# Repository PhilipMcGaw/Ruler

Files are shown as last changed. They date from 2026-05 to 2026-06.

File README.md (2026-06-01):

# Ruler

A KiCad PCB ruler that doubles as a desk reference for SMD footprints, drill sizes, and trace widths—and includes a small ATtiny85 circuit to light five LEDs. Designed by [Philip McGaw](https://philipmcgaw.com).

The board is roughly **100 mm** long and combines measurement scales with populated example parts you can touch, compare, and (optionally) program.

## Features

### Measurement & reference

- **Metric** and **imperial** ruler scales (including 1/8″ and 1/10″ subdivisions)
- **Degree / protractor** scale for rough angle checks
- **Drill hole** reference sizes
- **Trace width** and **font size** guides (mm and mil)
- **SMD resistor** footprints from 0201 through 2512, with separate **hand-solder** and **machine-solder** pad variants
- **SMD LED** examples (0201, 0402, 0603, 0805, 1206)
- **Test points** labelled for common pad/hole diameters (1.0–2.5 mm)

### Electronics

| Item | Details |
|---|---|
| MCU | ATtiny85V-10SU (SOIJ-8) |
| LEDs | Five, one per common SMD size (red 1206, green 0402, yellow 0603, orange 0805, blue 0201) |
| Power | CR2032 coin cell (Keystone 3002 holder) |
| Programming | 2×3 pin header (`J1`, labelled ICP6) for in-circuit programming |

The populated LEDs are driven by the ATtiny85. **Firmware is not included in this repository**—you will need to write and flash your own sketch (e.g. with [Arduino IDE + ATTinyCore](https://github.com/SpenceKonde/ATTinyCore) or `avrdude` via the ISP header).

> **Note:** This ruler is intended as a **reference and teaching aid**, not a calibrated measuring instrument.

## Repository layout

```
KiCAD/
├── ruler.kicad_pro      # KiCad project
├── ruler.kicad_sch      # Schematic
├── ruler.kicad_pcb      # Board layout
├── Common/              # Project symbols, footprints, design blocks
│   ├── Symbols.kicad_sym
│   ├── Footprints/      # Custom footprints (SquashedFly — https://squashedfly.eu/)
│   └── Design Blocks/
├── Libraries/           # Additional third-party symbol/footprint libraries
├── sym-lib-table
├── fp-lib-table
└── design-block-lib-table
```

Gerber output is configured to write to `KiCAD/Gerber/` when you plot from Pcbnew.

## Requirements

- **[KiCad](https://www.kicad.org/)** 9 or 10 (project files were last saved with KiCad 10)
- **PCBRulers** footprint library — the board uses footprints such as `PCBRulers:Metric_Ruler_96mm`, `PCBRulers:Inch_Ruler_3.5in_10`, `PCBRulers:Drills`, and `PCBRulers:Degree_Scale`. Install the [PCBruler](https://github.com/jbtronics/PCBruler) library (or equivalent) and add it to your KiCad footprint library path if footprints appear missing.
- Standard KiCad libraries for passives, connectors, batteries, and the ATtiny symbol (project rescue lib `ruler-rescue` is embedded in the schematic)

## Opening the project

1. Clone this repository.
2. Open `KiCAD/ruler.kicad_pro` in KiCad.
3. If prompted about missing libraries, confirm that `Common/` paths resolve (they use `${KIPRJMOD}`) and that **PCBRulers** is installed globally or added to `fp-lib-table`.

Project-local tables already point at bundled assets:

- Symbols: `Common/Symbols.kicad_sym`, Partsbox HTTP lib
- Footprints: `Common/Footprints/`

## Building the board

1. Run **Design Rules Check** (DRC) in Pcbnew and resolve any issues for your fab’s capabilities.
2. Generate manufacturing files: **File → Plot** (Gerbers) and **File → Fabrication Outputs → Drill Files**.
3. Order from your preferred PCB fab. For best readability of the silkscreen scales and contact details, **ENIG** finish and a dark soldermask are commonly used on similar rulers.

Populate the optional electronics if you want the LED demo to work; the ruler scales and footprint references are useful even unpopulated.

## Programming the ATtiny85

1. Connect an ISP programmer to `J1` (6-pin, 2.54 mm pitch, 2×3).
2. Power the board from the CR2032 cell or according to your programmer’s requirements.
3. Flash firmware with your toolchain of choice.

Pin mapping and LED connections are defined in `ruler.kicad_sch` / `ruler.kicad_pcb`.

## Credits

- **Design:** Philip McGaw — [philipmcgaw.com](https://philipmcgaw.com) · [GitHub](https://github.com/PhilipMcGaw)
- **[SquashedFly](https://squashedfly.eu/)** — title block worksheet (`KiCAD/Common/Squashed Fly.kicad_wks`) and optional PCB logo footprints (`SquashedFlySilk`, `SquashedFlyCopper`, etc.) in `KiCAD/Common/Footprints/`
- Ruler scale footprints from the **PCBRulers** / [PCBruler](https://github.com/jbtronics/PCBruler) ecosystem

## License

Hardware design files in this repository are licensed under the **[CERN Open Hardware Licence v2 — Strongly Reciprocal (CERN-OHL-S-2.0)](LICENSE)**, an open source hardware license recommended by the [Open Source Hardware Association (OSHWA)](https://oshwa.org/).

- **SPDX identifier:** `CERN-OHL-S-2.0`
- **Copyright:** [Philip McGaw](https://philipmcgaw.com/)
- **Full text:** [LICENSE](LICENSE)

You may use, study, modify, and redistribute the schematic and PCB layout under those terms. **Derivative designs must be released under the same license.** If you share the design or boards built from it, include a copy of the license.

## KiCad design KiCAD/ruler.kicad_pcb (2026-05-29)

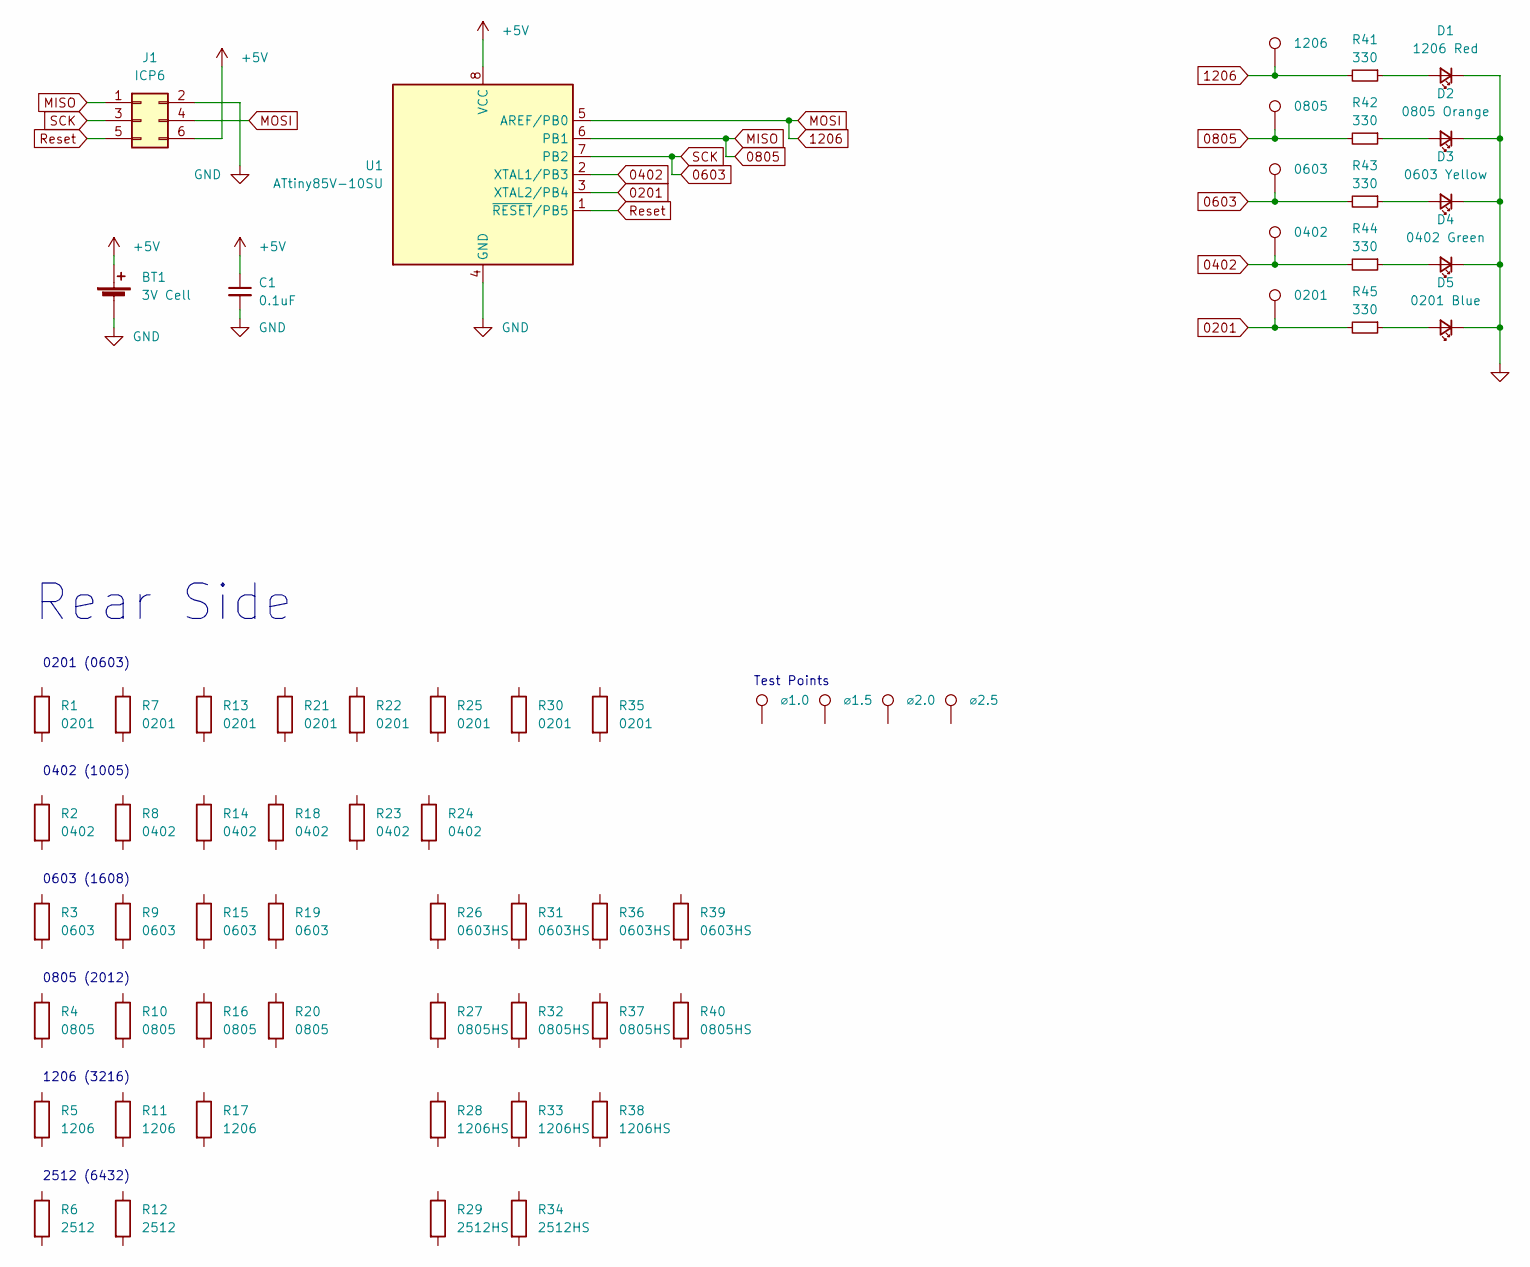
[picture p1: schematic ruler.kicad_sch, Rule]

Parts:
BT1: 3V Cell; BatteryHolder_Keystone_3002_1x2032
C1: 0.1uF; C_0805_2012Metric_Pad1.15x1.40mm_HandSolder
D1: 1206 Red; LED_1206_3216Metric_Pad1.42x1.75mm_HandSolder
D2: 0805 Orange; LED_0805_2012Metric_Pad1.15x1.40mm_HandSolder
D3: 0603 Yellow; LED_0603_1608Metric_Pad1.05x0.95mm_HandSolder
D4: 0402 Green; LED_0402_1005Metric
D5: 0201 Blue; LED_0201_0603Metric
J1: ICP6; PinHeader_2x03_P2.54mm_Vertical
R1, R7, R13, R21, R22, R25, R30, R35: 0201; R_0201_0603Metric
R2, R8, R14, R18, R23, R24: 0402; R_0402_1005Metric
R3, R9, R15, R19: 0603; R_0603_1608Metric
R4, R10, R16, R20: 0805; R_0805_2012Metric
R5, R11, R17: 1206; R_1206_3216Metric
R6, R12: 2512; R_2512_6332Metric
R26, R31, R36, R39: 0603HS; R_0603_1608Metric_Pad0.98x0.95mm_HandSolder
R27, R32, R37, R40: 0805HS; R_0805_2012Metric_Pad1.20x1.40mm_HandSolder
R28, R33, R38: 1206HS; R_1206_3216Metric_Pad1.30x1.75mm_HandSolder
R29, R34: 2512HS; R_2512_6332Metric_Pad1.40x3.35mm_HandSolder
R41: 330; R_1206_3216Metric_Pad1.42x1.75mm_HandSolder
R42: 330; R_0805_2012Metric_Pad1.20x1.40mm_HandSolder
R43: 330; R_0603_1608Metric_Pad0.98x0.95mm_HandSolder
R44: 330; R_0402_1005Metric
R45: 330; R_0201_0603Metric
TP1: ⌀1.0; TestPoint_Pad_D1.0mm
TP2: ⌀1.5; TestPoint_Pad_D1.5mm
TP3: ⌀2.0; TestPoint_Pad_D2.0mm
TP4: ⌀2.5; TestPoint_Pad_D2.5mm
TP5: 1206; TestPoint_Pad_D1.0mm
TP6: 0805; TestPoint_Pad_D1.0mm
TP7: 0603; TestPoint_Pad_D1.0mm
TP8: 0402; TestPoint_Pad_D1.0mm
TP9: 0201; TestPoint_Pad_D1.0mm
U1: ATtiny85V-10SU; SOIJ-8_5.3x5.3mm_P1.27mm

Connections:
0201: R45.2, TP9.1 (1_1), U1.3 (XTAL2/PB4)
0402: R44.2, TP8.1 (1_1), U1.2 (XTAL1/PB3)
0603: J1.3, R43.2, TP7.1 (1_1), U1.7 (PB2)
0805: J1.1, R42.2, TP6.1 (1_1), U1.6 (PB1)
1206: J1.4, R41.2, TP5.1 (1_1), U1.5 (AREF/PB0)
+5V: BT1.1 (+), C1.1, J1.6, U1.8 (VCC)
GND: BT1.2 (-), C1.2, D1.1 (K), D2.1 (K), D3.1 (K), D4.1 (K), D5.1 (K), J1.2, U1.4 (GND)
unnamed: D1.2 (A), R41.1
unnamed: D2.2 (A), R42.1
unnamed: D3.2 (A), R43.1
unnamed: D4.2 (A), R44.1
unnamed: D5.2 (A), R45.1
Reset: J1.5, U1.1 (~RESET/PB5)

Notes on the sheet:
0201 (0603)
1206 (3216)
0402 (1005)
Rear Side
Test Points
0805 (2012)
0603 (1608)
2512 (6432)

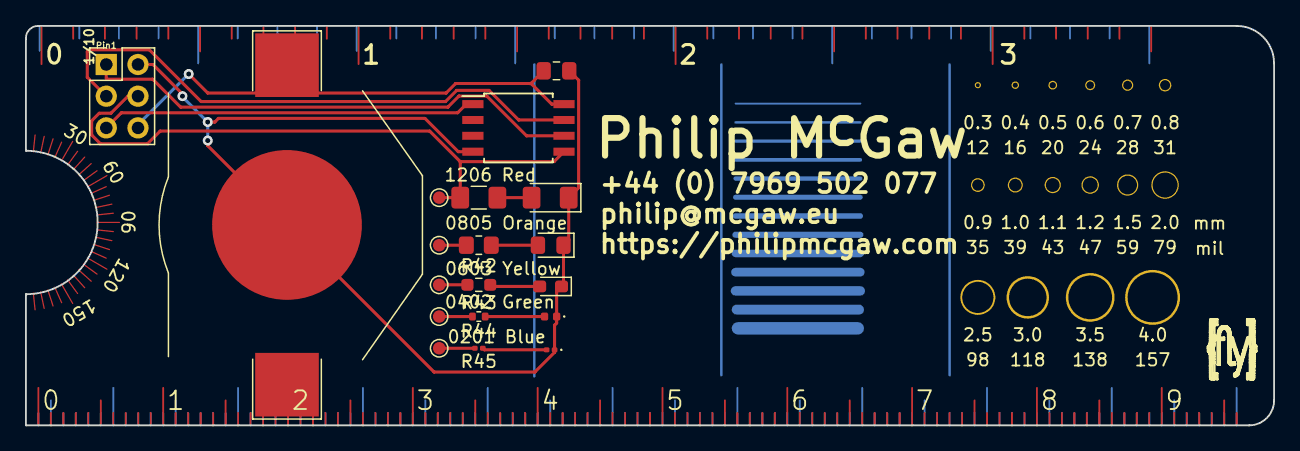
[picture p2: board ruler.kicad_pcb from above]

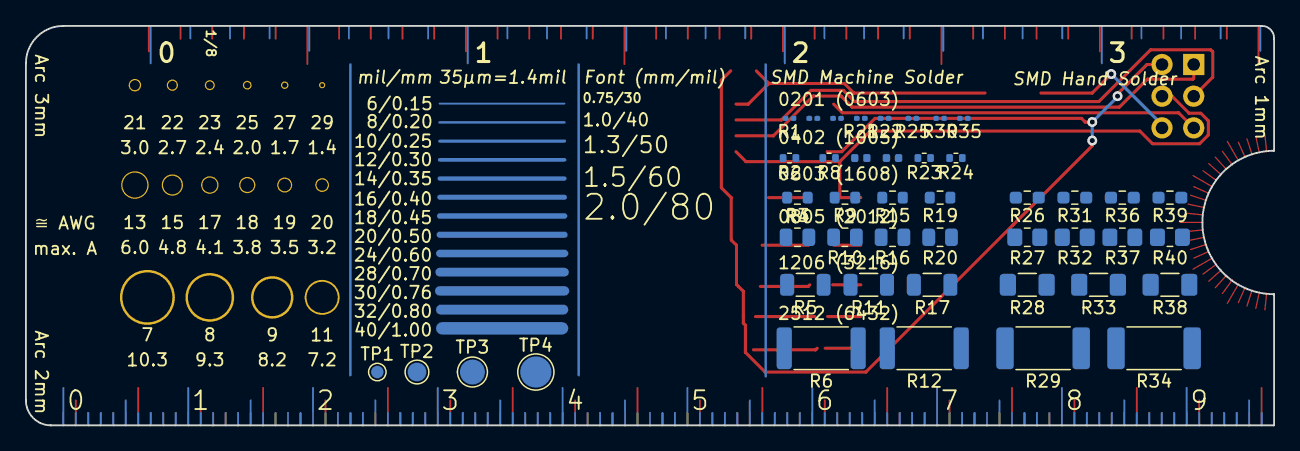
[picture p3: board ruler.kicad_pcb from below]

Board: 2 copper layers, 100.0 x 32.0 mm, 63 parts (44 on the bottom side), 13 nets.

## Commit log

2026-05-28 to fix
    [business card-B_Cu.gbl, business card-B_Mask.gbs, business card-B_Paste.gbp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]
2026-05-29 change libs
    [Arduino CAN.kicad_sch, LED - CXA1304.step, LED Cube.kicad_sch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]
2026-07-24 removed common
    [Arduino CAN.kicad_sch, LED - CXA1304.step, LED Cube.kicad_sch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]
